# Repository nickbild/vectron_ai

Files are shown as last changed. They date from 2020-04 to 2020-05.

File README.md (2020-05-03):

# Vectron AI

Train machines like it's 1979!

Vectron AI interfaces with the [Vectron 64](https://github.com/nickbild/vectron_64) breadboard computer (6502 CPU @ 1MHz, 32KB RAM, 32KB ROM) to provide gesture detecting artificial intelligence.  The gesture detection is used to control an Atari 2600 emulator.

<p align="center">
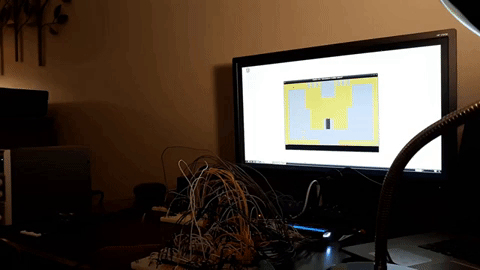
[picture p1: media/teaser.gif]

</p>

## How It Works

Images are captured, downscaled, and converted to an integer vector by a Raspberry Pi 3 B+.  The vector is then transferred, one byte at a time, to a shift register in Vectron AI.  After each byte is loaded, an interrupt is sent to the Vectron 64 computer.

The Vectron 64 retrieves each byte and stores it in RAM.  When a full image has been received, it runs a k-nearest neighbors algorithm to classify the current image against 50 known images that are stored in the ROM.  The class of the best match (minimum sum of all pixel distances) determines the predicted class of the current image.  The 6502 assembly can be found [here](https://github.com/nickbild/vectron_ai/blob/master/vectron64.asm).

The Vectron 64 then puts an address on the address bus that Vectron AI interprets and in turn sends a signal to a GPIO pin on another Raspberry Pi 3 B+.  This Raspberry Pi is running a [script](https://github.com/nickbild/vectron_ai/blob/master/play_atari.py) that converts the GPIO signal to a simulated keypress.  The simulated keypress controls a [Stella](https://stella-emu.github.io/) Atari 2600 emulator (I suspect it would be only a small task to feed the GPIO directly into the joystick port of a real Atari 2600, but I don't have one available at present).

When this is all put together, you can place your hand in front of the camera with any of the known gestures (e.g. "up", "down", "left", "right"), and the game will be controlled accordingly.

## Media

Youtube video:  
https://www.youtube.com/watch?v=HILEYKIFixw

First, some examples of downscaled images that the Vectron 64 processes.  They have a beautiful 8-bit appearance.  As someone with more experience working with higher resolution images on artificial neural networks, I was a bit shocked by how accurate a simple algorithm like k-nearest neighbors is for image classification, and with very low resolution inputs.

Hand gesturing "up":

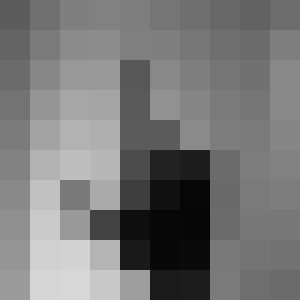
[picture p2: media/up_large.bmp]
up


Hand gesturing "right":

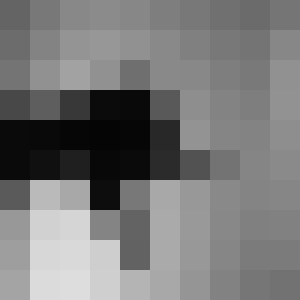
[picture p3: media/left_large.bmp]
left


The full setup:

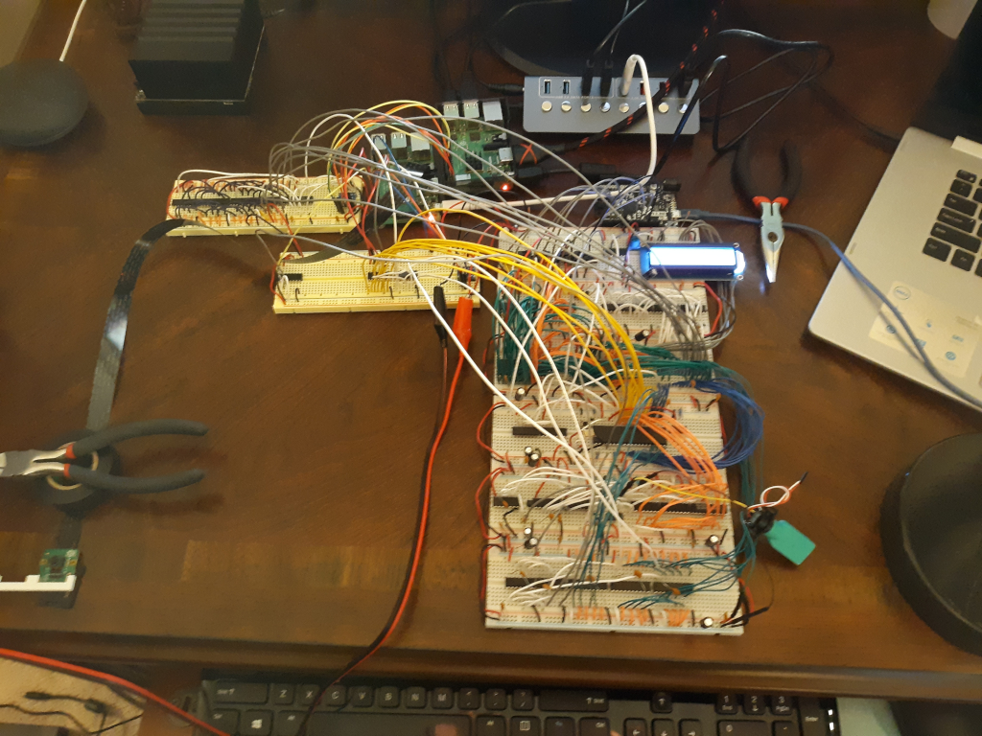
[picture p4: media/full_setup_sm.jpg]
full_setup


Close-up of the AI module:

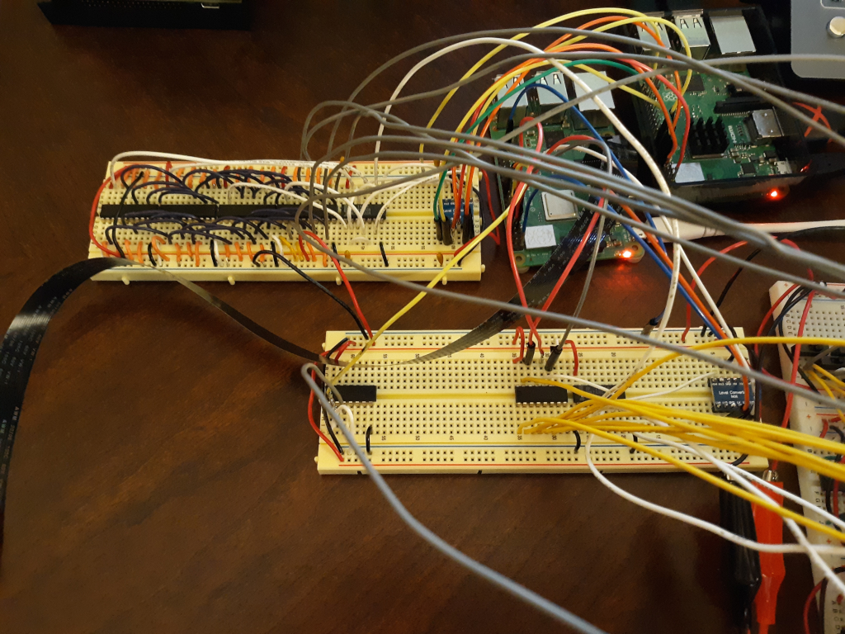
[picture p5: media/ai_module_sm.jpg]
ai_module


The camera:

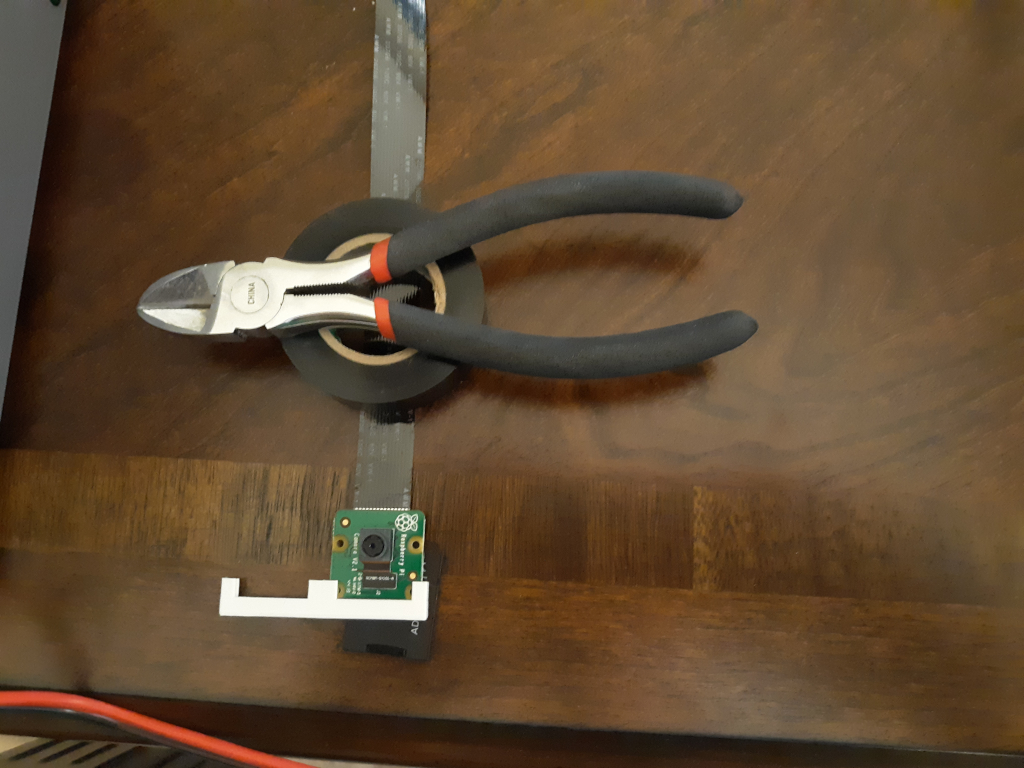
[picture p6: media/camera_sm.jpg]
camera


Circuit diagram:

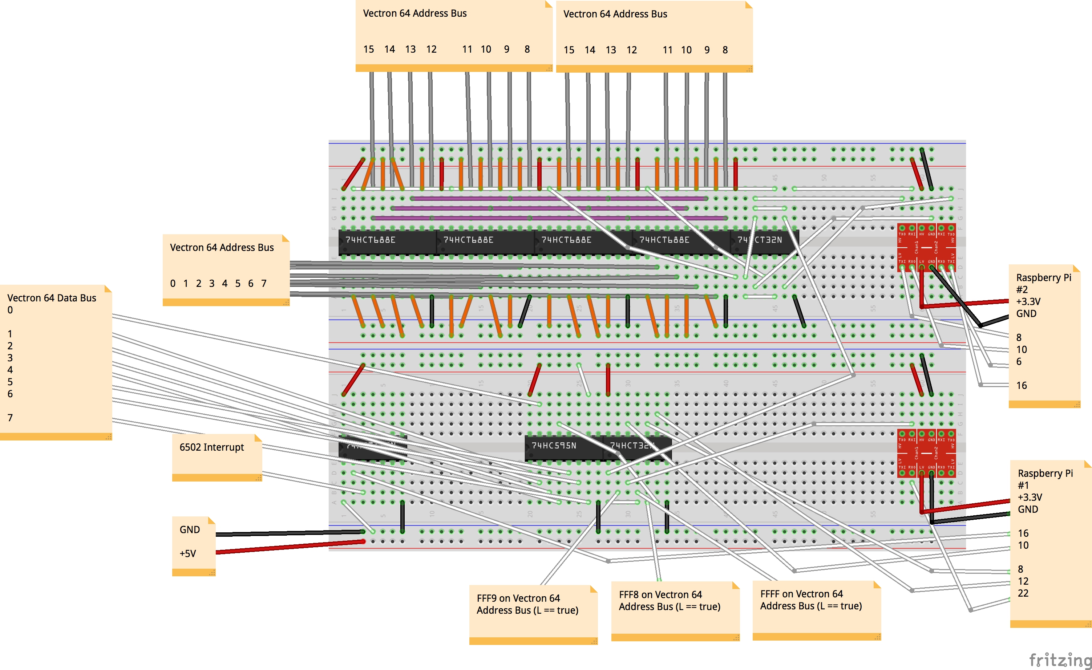
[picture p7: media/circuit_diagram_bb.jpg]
circuit


[Fritzing Download](https://raw.githubusercontent.com/nickbild/vectron_ai/master/media/circuit_diagram.fzz)

## Bill of Materials

- 1 x [Vectron 64](https://github.com/nickbild/vectron_64)
- 2 x Raspberry Pi 3 Model B+
- 1 x Raspberry Pi Camera v2
- 1 x Logic Level Shifter (3.3V -> 5V)
- 2 x Logic Level Shifter (5V -> 3.3V)
- 2 x 74HC32 Quad OR Gate
- 1 x 74HC595 Shift Register
- 4 x 74HCT688E Logic Comparator
- 1 x Miscellaneous Wire

## About the Author

[Nick A. Bild, MS](https://nickbild79.firebaseapp.com/#!/)

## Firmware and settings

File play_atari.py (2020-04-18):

####
# Nick Bild
# nick.bild@gmail.com
# Control Atari 2600 emulator via GPIO.
####
import RPi.GPIO as GPIO
import pyautogui
import time


key_hold_time_sec = 0.1

up = 8
down = 10
left = 12
right = 16

GPIO.setmode(GPIO.BOARD)

GPIO.setup(up, GPIO.IN)
GPIO.setup(down, GPIO.IN)
GPIO.setup(left, GPIO.IN)
GPIO.setup(right, GPIO.IN)

GPIO.add_event_detect(up, GPIO.FALLING)
GPIO.add_event_detect(down, GPIO.FALLING)
GPIO.add_event_detect(left, GPIO.FALLING)
GPIO.add_event_detect(right, GPIO.FALLING)


while True:
    # Check for an input
    if GPIO.event_detected(up) == True:
        pyautogui.keyDown('up')
        time.sleep(key_hold_time_sec)
        pyautogui.keyUp('up')

    if GPIO.event_detected(down) == True:
        pyautogui.keyDown('down')
        time.sleep(key_hold_time_sec)
        pyautogui.keyUp('down')

    if GPIO.event_detected(left) == True:
        pyautogui.keyDown('left')
        time.sleep(key_hold_time_sec)
        pyautogui.keyUp('left')

    if GPIO.event_detected(right) == True:
        pyautogui.keyDown('right')
        time.sleep(key_hold_time_sec)
        pyautogui.keyUp('right')

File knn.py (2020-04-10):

import glob
import sys
import operator


vectors = []
labels = []


def threshold(v):
    if v < 10:
        v = 0
    elif v < 20:
        v = 1
    elif v < 30:
        v = 2
    elif v < 40:
        v = 3
    elif v < 50:
        v = 4
    else:
        v = 5

    return v


def load_training_data():
    files = glob.glob("train/*/image_*.txt")
    for file in files:
        label = file.split("/")[-2]
        with open(file, "r") as f:
            vector = []
            for line in f:
                line = int(line.strip())
                line = threshold(line)
                vector.append(line)
            vectors.append(vector)
            labels.append(label)
    return


def load_single_image(file):
    vector = []

    with open(file, "r") as f:
        for line in f:
            line = int(line.strip())
            line = threshold(line)
            vector.append(line)

    return vector


def calculate_distances_to_new_point(new_vector):
    results = {}

    for i in range(len(vectors)):
        distance = 0
        for j in range(len(vectors[i])):
            distance += abs(vectors[i][j] - new_vector[j])

        results["{}_{}".format(labels[i], distance)] = distance

    return results


if __name__ == "__main__":
    load_training_data()

    v = load_single_image(sys.argv[1])
    results = calculate_distances_to_new_point(v)

    sorted = sorted(results.items(), key=operator.itemgetter(1))

    for s in sorted:
        print(s)

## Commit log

2020-04-11 Test shift register and interrupt.
2020-04-12 Fix interrupt_clear detection.
2020-04-14 Fix memory addressing issue.
    [vectron64.asm]
2020-04-14 Set carry flag properly for adc and sbc.
2020-04-15 Fix RAM variable overwrite issue.
    [vectron64.asm]
2020-04-16 Correct interrupt logic.
2020-04-17 Swap SR and interrupt clear signals - it's working.
    [vectron64.asm]
2020-04-17 Switch to PyAutoGUI.
2020-05-03 Add circuit diagram.
    [circuit_diagram.fzz]
2020-05-03 Update circuit diagram.
    [circuit_diagram.fzz]
